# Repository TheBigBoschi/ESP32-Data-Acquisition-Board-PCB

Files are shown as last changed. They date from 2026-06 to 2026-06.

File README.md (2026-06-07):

# ESP32-Data-Acquisition-Board-PCB
Custom PCB holding an ESP32, various sensor, a LoRa transmitter and the power management to run off a single lithium battery, charged by solar power.

To keep the development time short for this first revision I have made extensive use of various commercial modules, such as a TP4056 module, a few TPS63020 and a CN3791 to handle the power conversion. In the second revision they will be integrated directly on the board.

Particular care has been taken to properly decouple the ESP32 power supply, as a switching regulators are slow to react to the sudden bursts of energy required by the ESP32 transmitting data, and various capacitor have been added to give time to the regulator to respond.

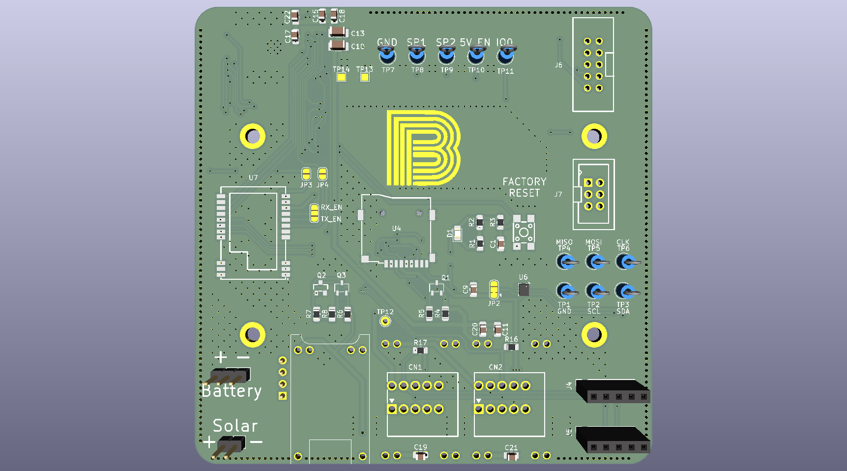
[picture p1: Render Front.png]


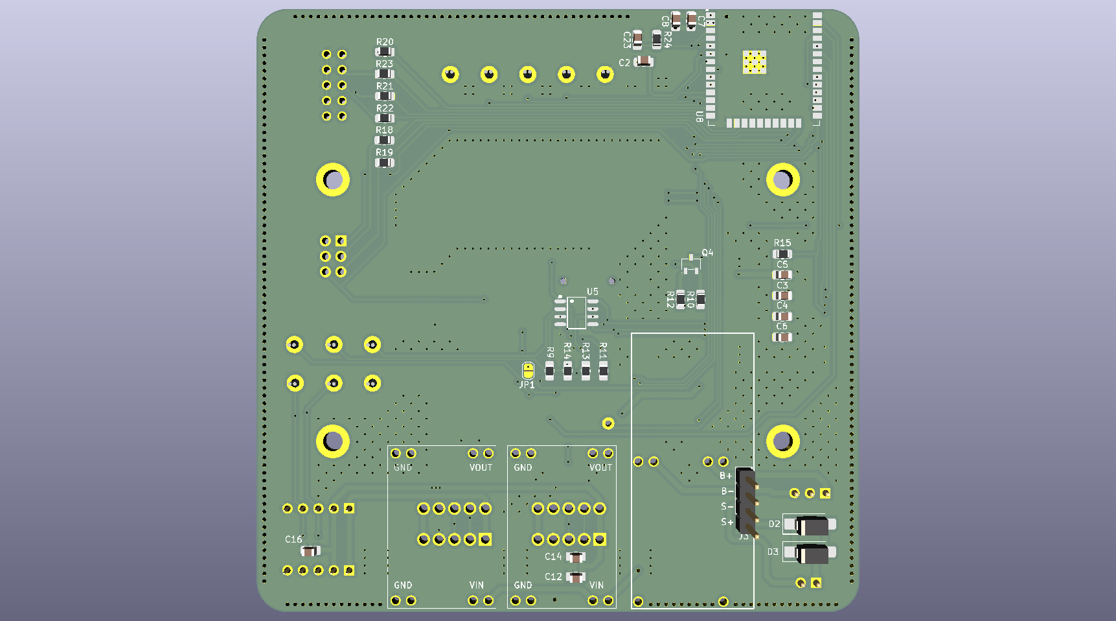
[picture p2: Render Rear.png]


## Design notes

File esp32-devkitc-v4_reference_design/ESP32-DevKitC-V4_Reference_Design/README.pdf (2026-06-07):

请使⽤用以下⼯工具打开原理理图和 PCB ⽂文件 / Use the following tools to open schematics and PCB files: SCH: Cadence/OrCAD Capture V16.6
PCB: Mentor Graphics/Pads VⅩ.2

修订历史 / Revision History

- 2018.06
- 更更新原理理图和 BOM，移除 C15。更更多信息请查看 ESP32-DevKitC ⼊入⻔门指南。/ (http://esp-idf.readthedocs.io/en/latest/get-started/get-started-devkitc.html) Removed C15 from schematics and BOM list. More information can be found in ESP32-DevKitC Getting Started Guide.) (http://esp-idf.readthedocs.io/en/latest/get-started/get-started-devkitc.html)
- 增加针对 ESP32-WROOM-32D、ESP32-WROOM-32U 和 ESP32-SOLO-1 模组的 BOM。/ Added the BOM lists for modules ESP32-WROOM-32D, ESP32-WROOM-32U and ESP32-SOLO-1.
- 2018.01
- ⾸首次发布。/
First release.

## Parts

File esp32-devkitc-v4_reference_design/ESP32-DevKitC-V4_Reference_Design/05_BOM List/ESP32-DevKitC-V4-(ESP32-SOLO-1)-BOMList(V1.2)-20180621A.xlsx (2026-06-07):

ESP32-DevKitC-V4 BOMList(V1.2)
ID | Qty | Ref Des | Value | Package | ICs | Description
1 | 3 | C1, C3, C21 | 22 uF/10V (20%) | 0603 | Capacitor | Ceramic Capacitor
2 | 4 | C9, C14, C19, C22 | 0.1 uF/50V (10%) | 0402 | Capacitor | Ceramic Capacitor
3 | 1 | C20 | 4.7 uF/6.3V (10%) | 0402 | Capacitor | Ceramic Capacitor
4 | 1 | D1 | RED LED | 0603 | Diode | light-emitting diode: Red
5 | 1 | D2 | ESP-WROOM-32 | ESP32_MODULE | Module | ESP32-SOLO-1 (3.3V 32 Mbit)
6 | 1 | D3 | BAT760-7 | SOD323 | Diode | Schottky Diode, Vrrm=30V, Vr=21V, I=1A, IFSM=5.5A
7 | 3 | D4, D5, D6 | LESD5D5.0CT1G | SOD-523 | Diode | ESD, TVS Diode, 5V
8 | 1 | J1 | Micro USB Type B Female 5 Pin DIP/插件 | USB_5P | Connector | Micro USB
9 | 2 | Q1, Q2 | S8050 | SOT-23-3 | Transistor | Transistor
10 | 2 | R2, R24 | 2K (5%) | 0402 | Resistor | Chip Resistors
11 | 3 | R11, R21, R22 | 10K (5%) | 0402 | Resistor | Chip Resistors
12 | 2 | R17, R18 | 0R (5%) | 0402 | Resistor | Chip Resistors
13 | 1 | R25 | 22.1K (5%) | 0402 | Resistor | Chip Resistors
14 | 1 | R26 | 47.5K (5%) | 0402 | Resistor | Chip Resistors
15 | 2 | SW1, SW2 | SW push button | Tact Switch | Tact Switch | 复位按键，2 脚，3x4x2，贴片 (reset button, 2-pin, 3x4x2, SMT)
16 | 2 | J2, J3 | CON19X1_2P54 | CON19_2P54 | Connector | Male PCB Single Row Straight Header Connector, 2.54 mm Pitch, 19 Pins
17 | 1 | U1 | CP2102N-A01-GQFN28 | CP2102_QFN_28P | Interface ICs | USB-to-UART, USB2.0 full speed, data rate up to 3M baud
18 | 1 | U2 | AMS1117-3.3 | SOT-223 | Power ICs | LDO, 5V 转 3.3V 固定输出, 1A, SOT-223 (LDO, 5V/3.3V, 1A, SOT-223)

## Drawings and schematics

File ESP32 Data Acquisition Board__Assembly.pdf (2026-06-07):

## GND SP1 SP2 5V_EN IO0

# JP4 C13

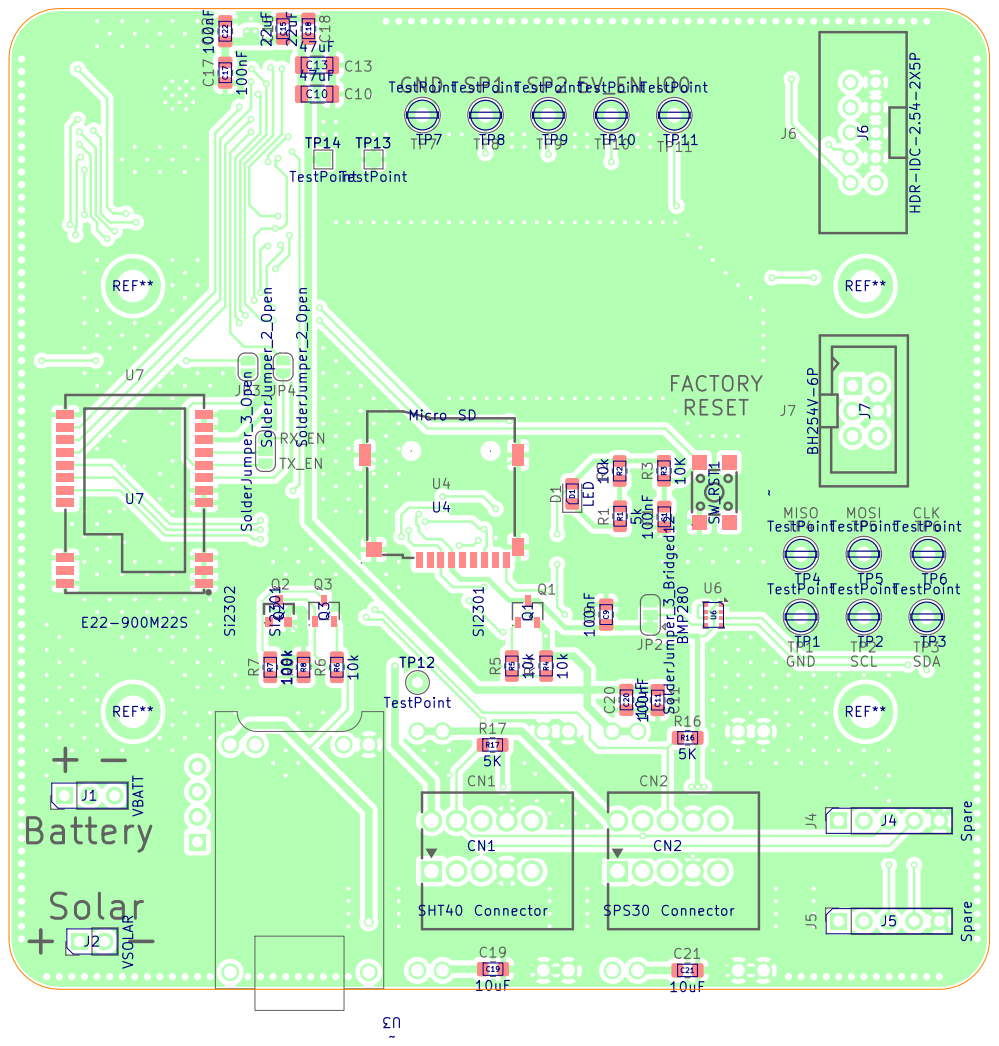
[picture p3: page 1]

Sheet: Colored TOP
File: ESP32 Data Acquisition Board.kicad_pcb
Title:
KiCad E.D.A. 10.0.3

ESP32-WROOM-32D U8 | M7F D2
C12 | 100nF C7 | CN3791 J3 10uF C8

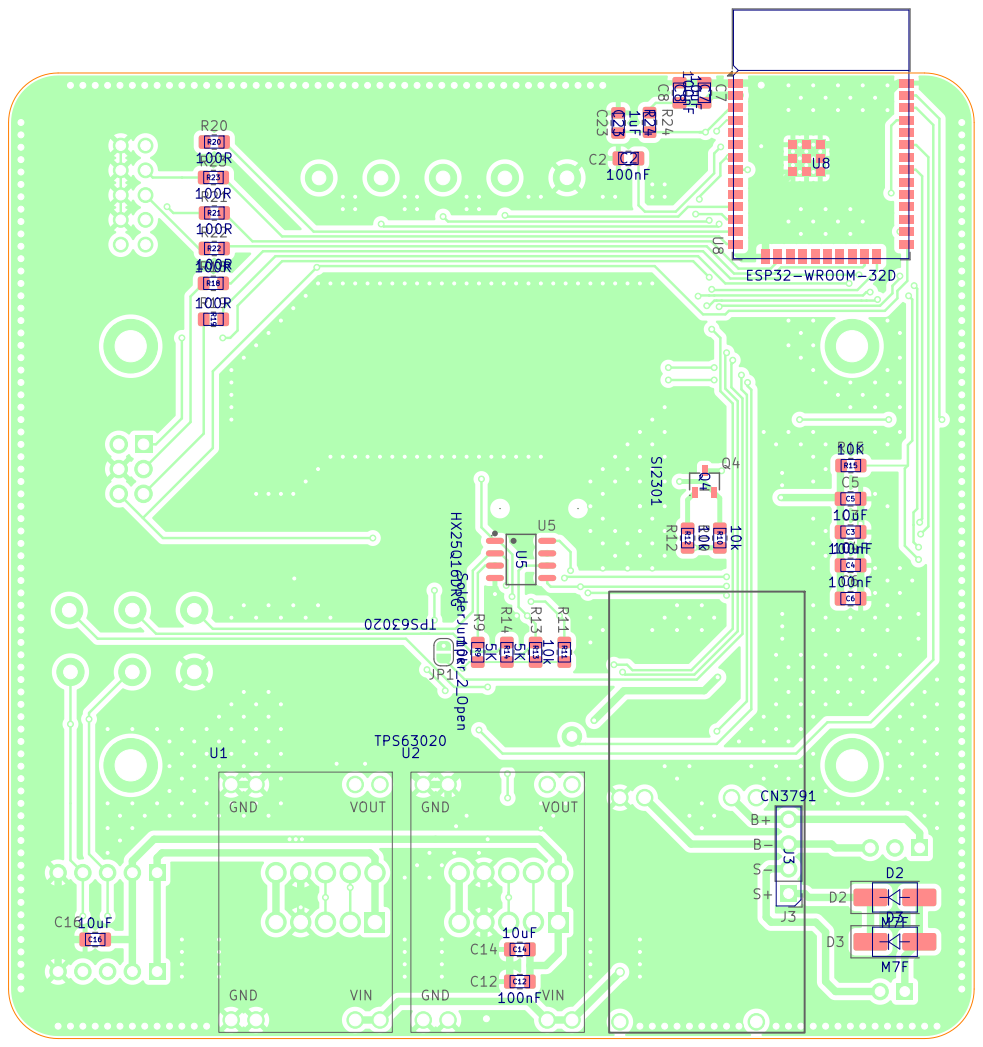
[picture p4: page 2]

Sheet: Colored BOT
File: ESP32 Data Acquisition Board.kicad_pcb
Title:
KiCad E.D.A. 10.0.3

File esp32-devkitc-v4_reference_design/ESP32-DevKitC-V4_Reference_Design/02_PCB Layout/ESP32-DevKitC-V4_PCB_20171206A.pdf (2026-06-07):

D1D¹x1 D¹x2 J2J2x1 J2x2 J2x3 J2x4 J2x5 J2x6 J2x7 J2x8 J2x9 J2x10 J2x11 J2x12 J2x13 J2x14 J2x15 J2x16 J2x17 J2x18 J2x19

J3J3x1 J3x2 J3x3 J3x4 J3x5 J3x6 J3x7 J3x8 J3x9 J3x10 J3x11 J3x12 J3x13 J3x14 J3x15 J3x16 J3x17 J3x18 J3x19

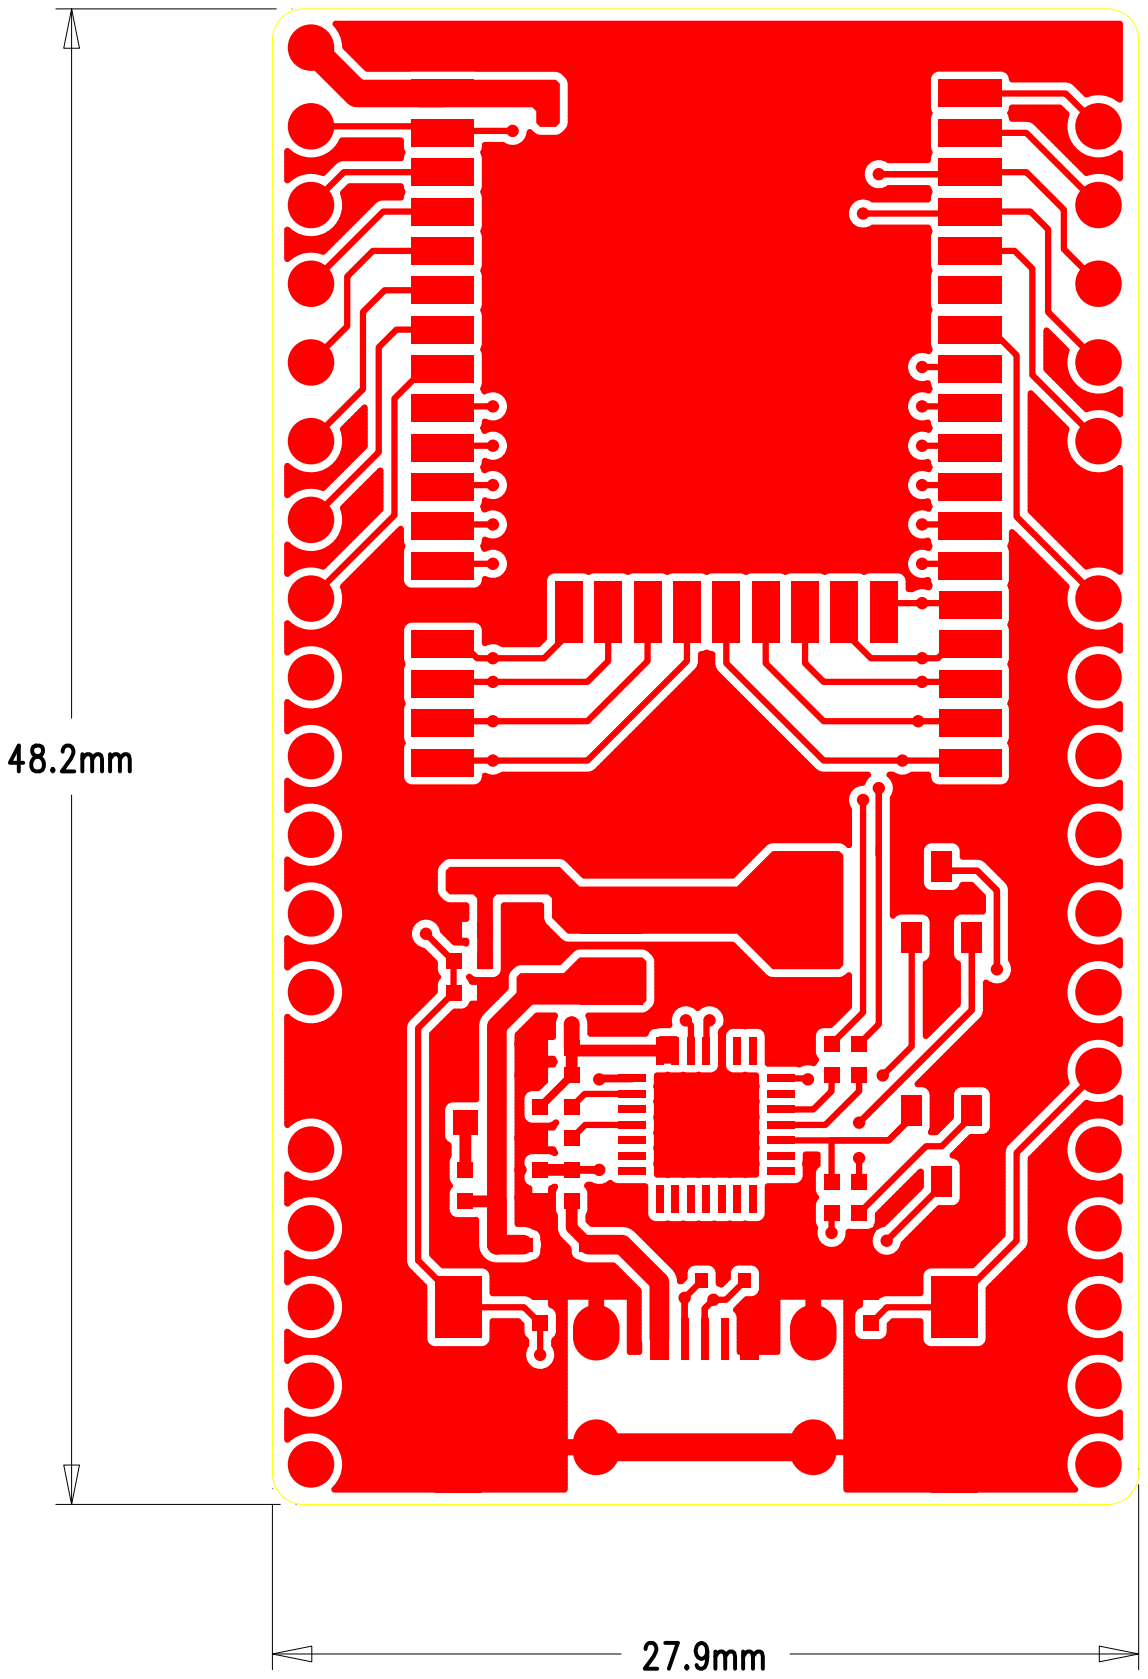
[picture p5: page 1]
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

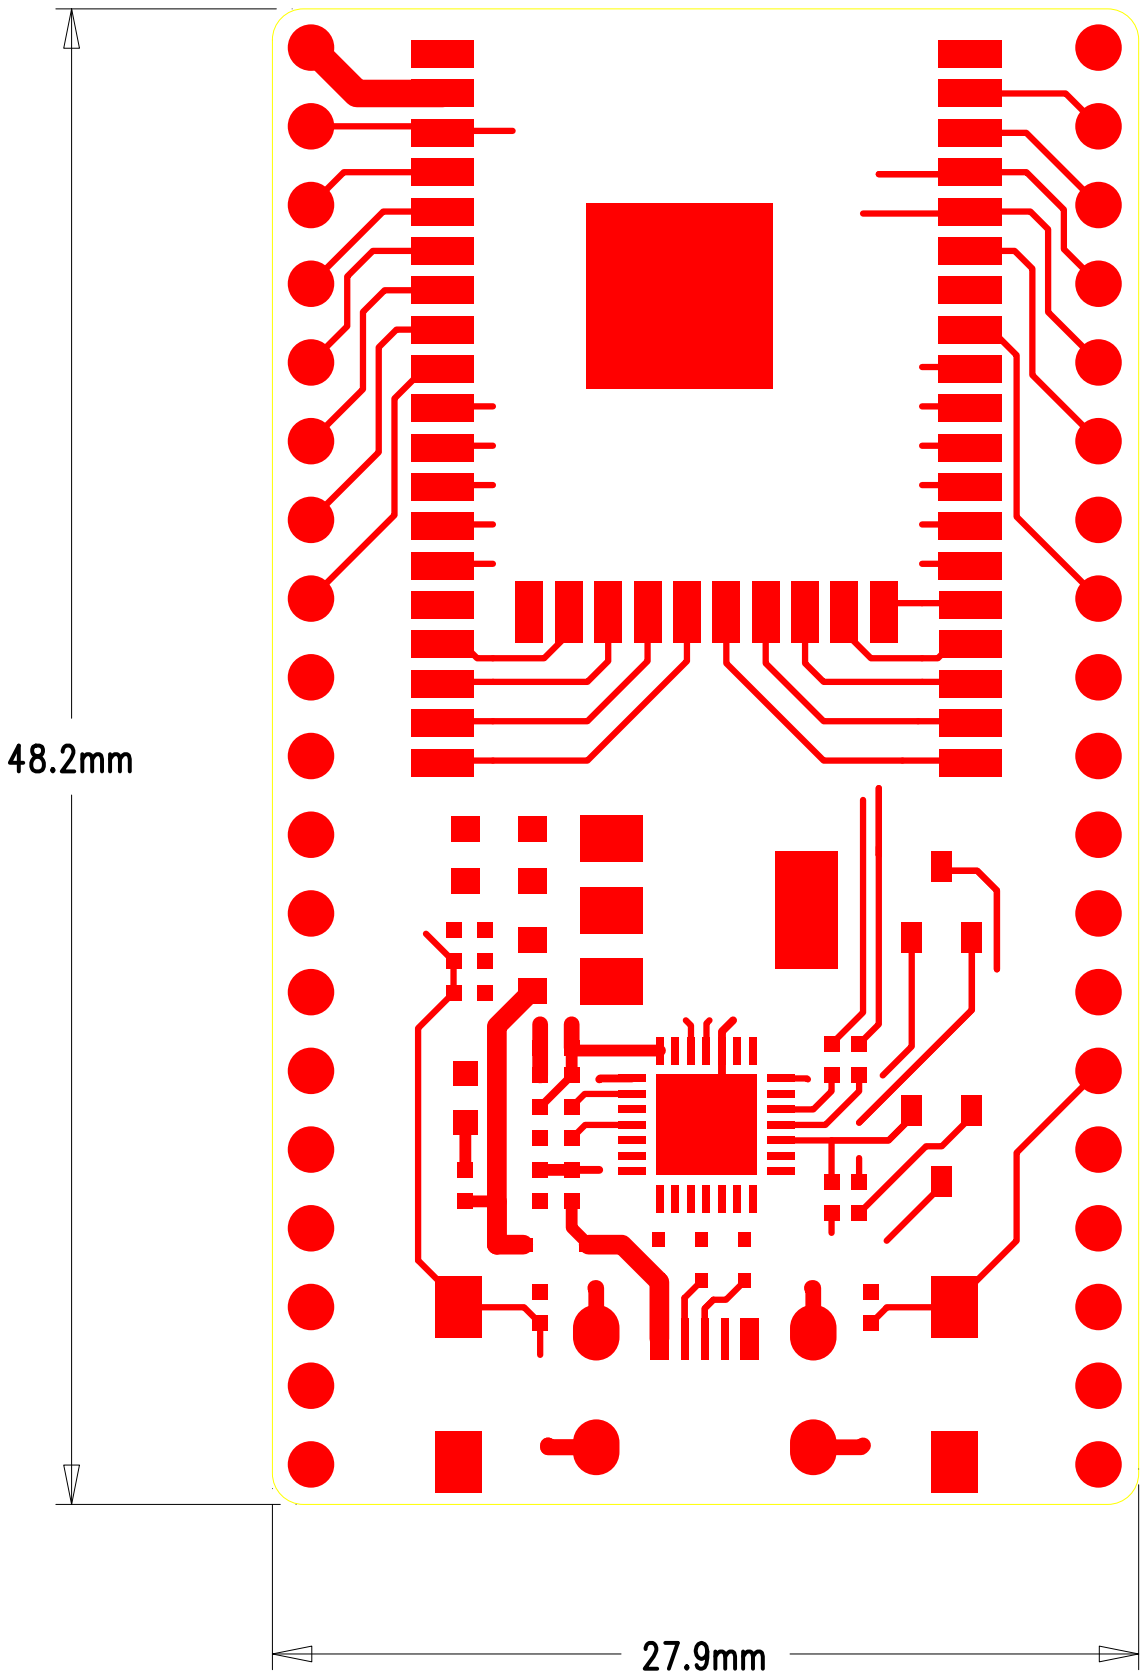
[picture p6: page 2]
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

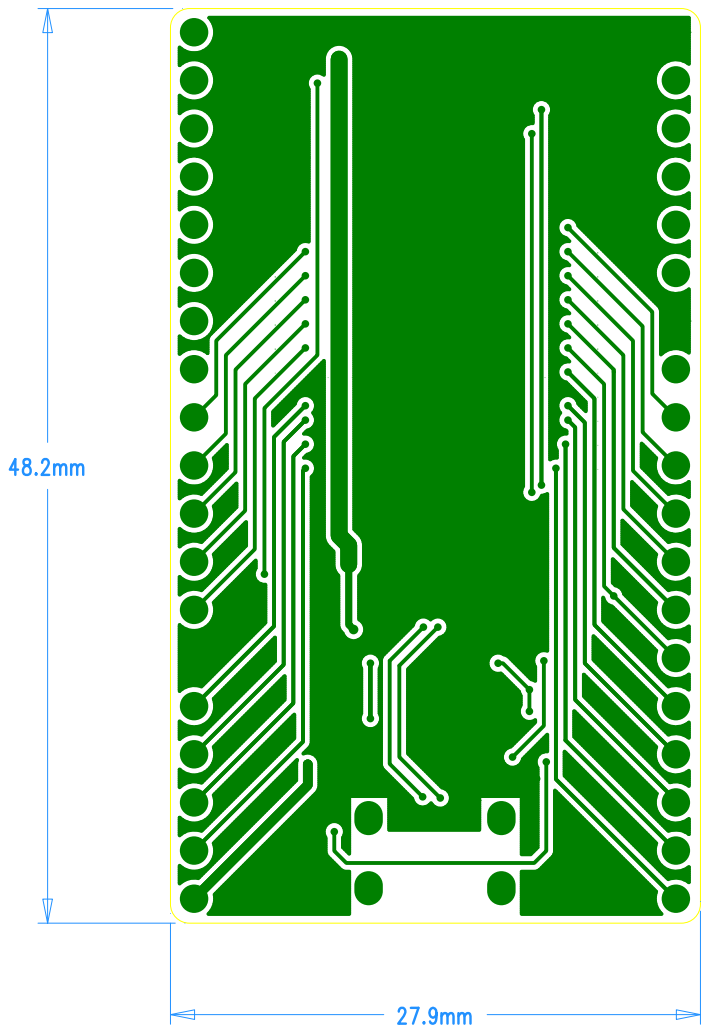
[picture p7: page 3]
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

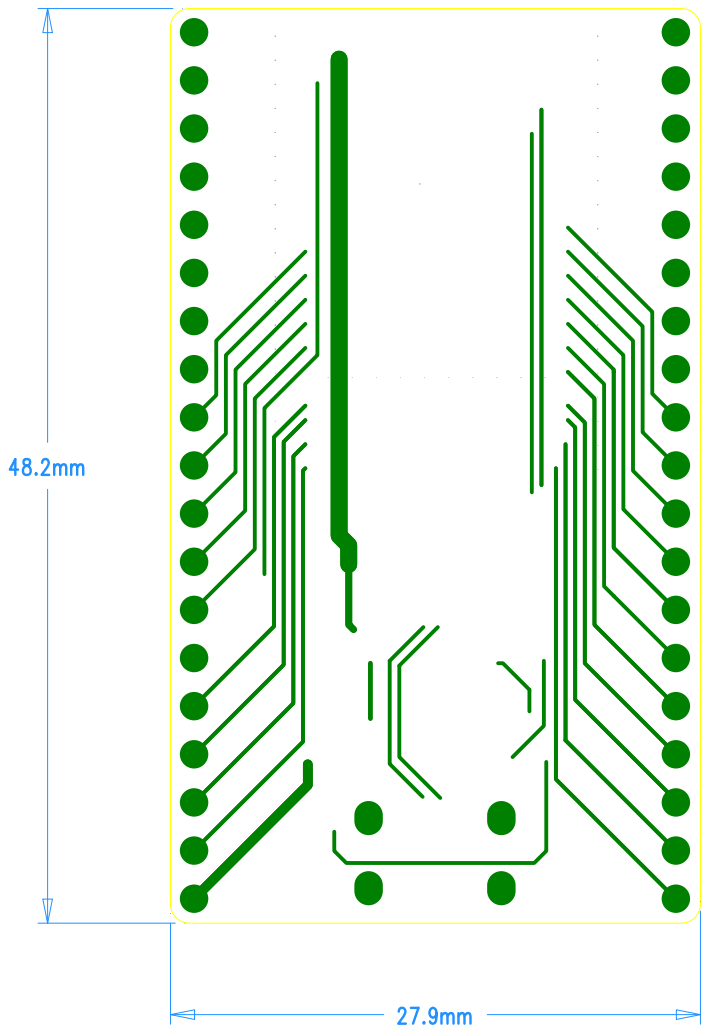
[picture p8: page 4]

# RF Antenna

D2

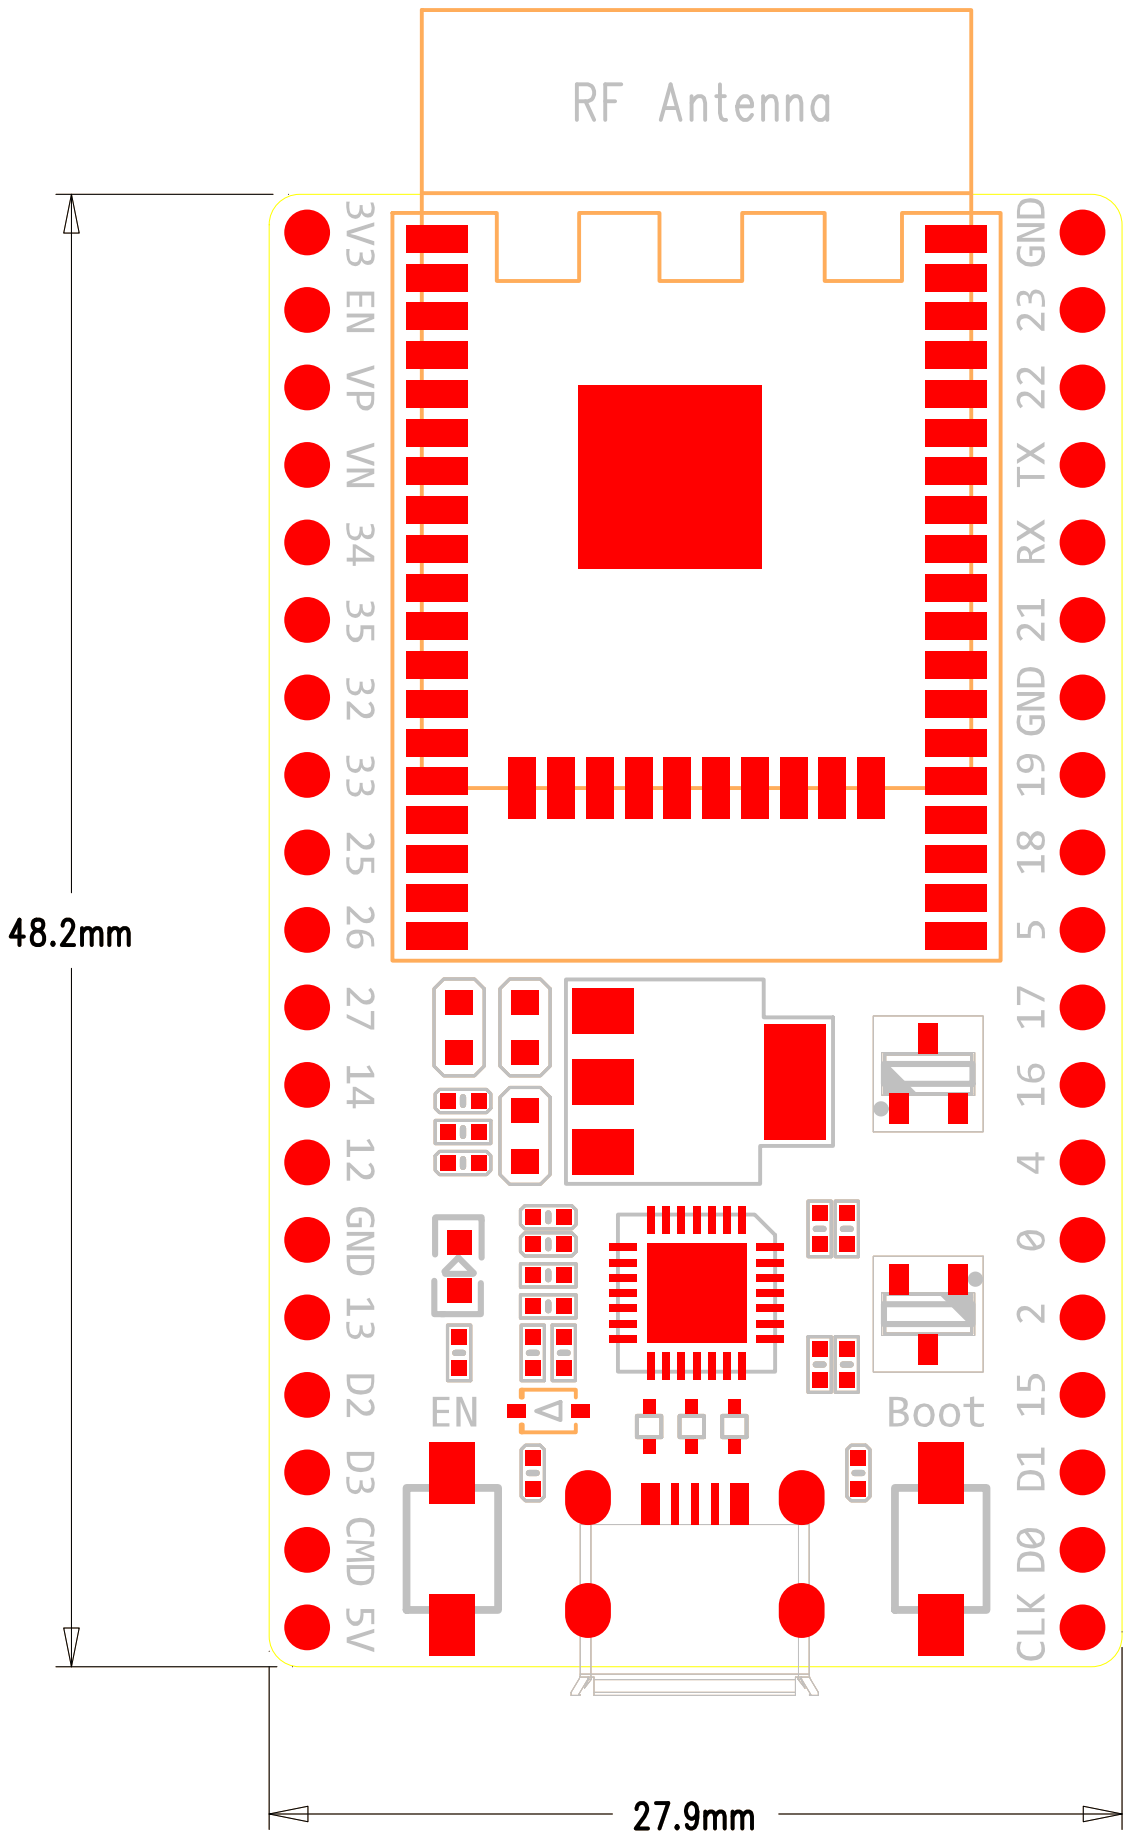
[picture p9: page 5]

3V3 EN VP VN 34 35 32 33 25 26 27 14 12 CMD 13 D2 D3 5V

GND 22 TX RX 21 GND 19 18 16 5 17 4 0 2 15 23 CLK D0 D1

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

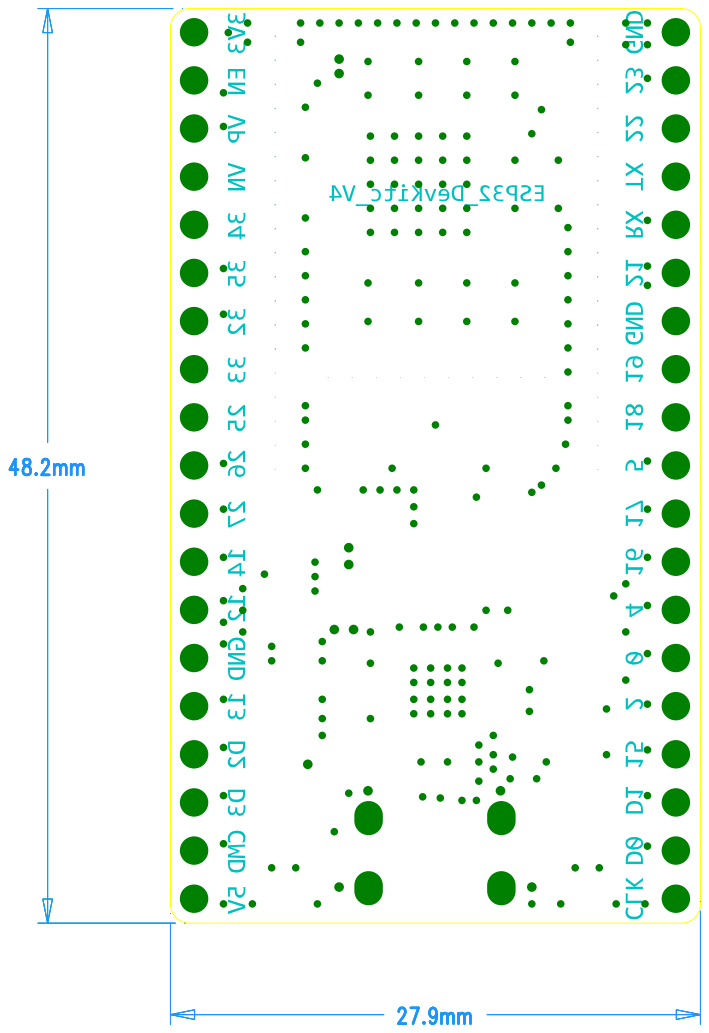
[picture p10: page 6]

3V3 EN VP VN 34 35 32 33 25 26 27 14 12 GND 13 D2 D3 CMD 5V

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

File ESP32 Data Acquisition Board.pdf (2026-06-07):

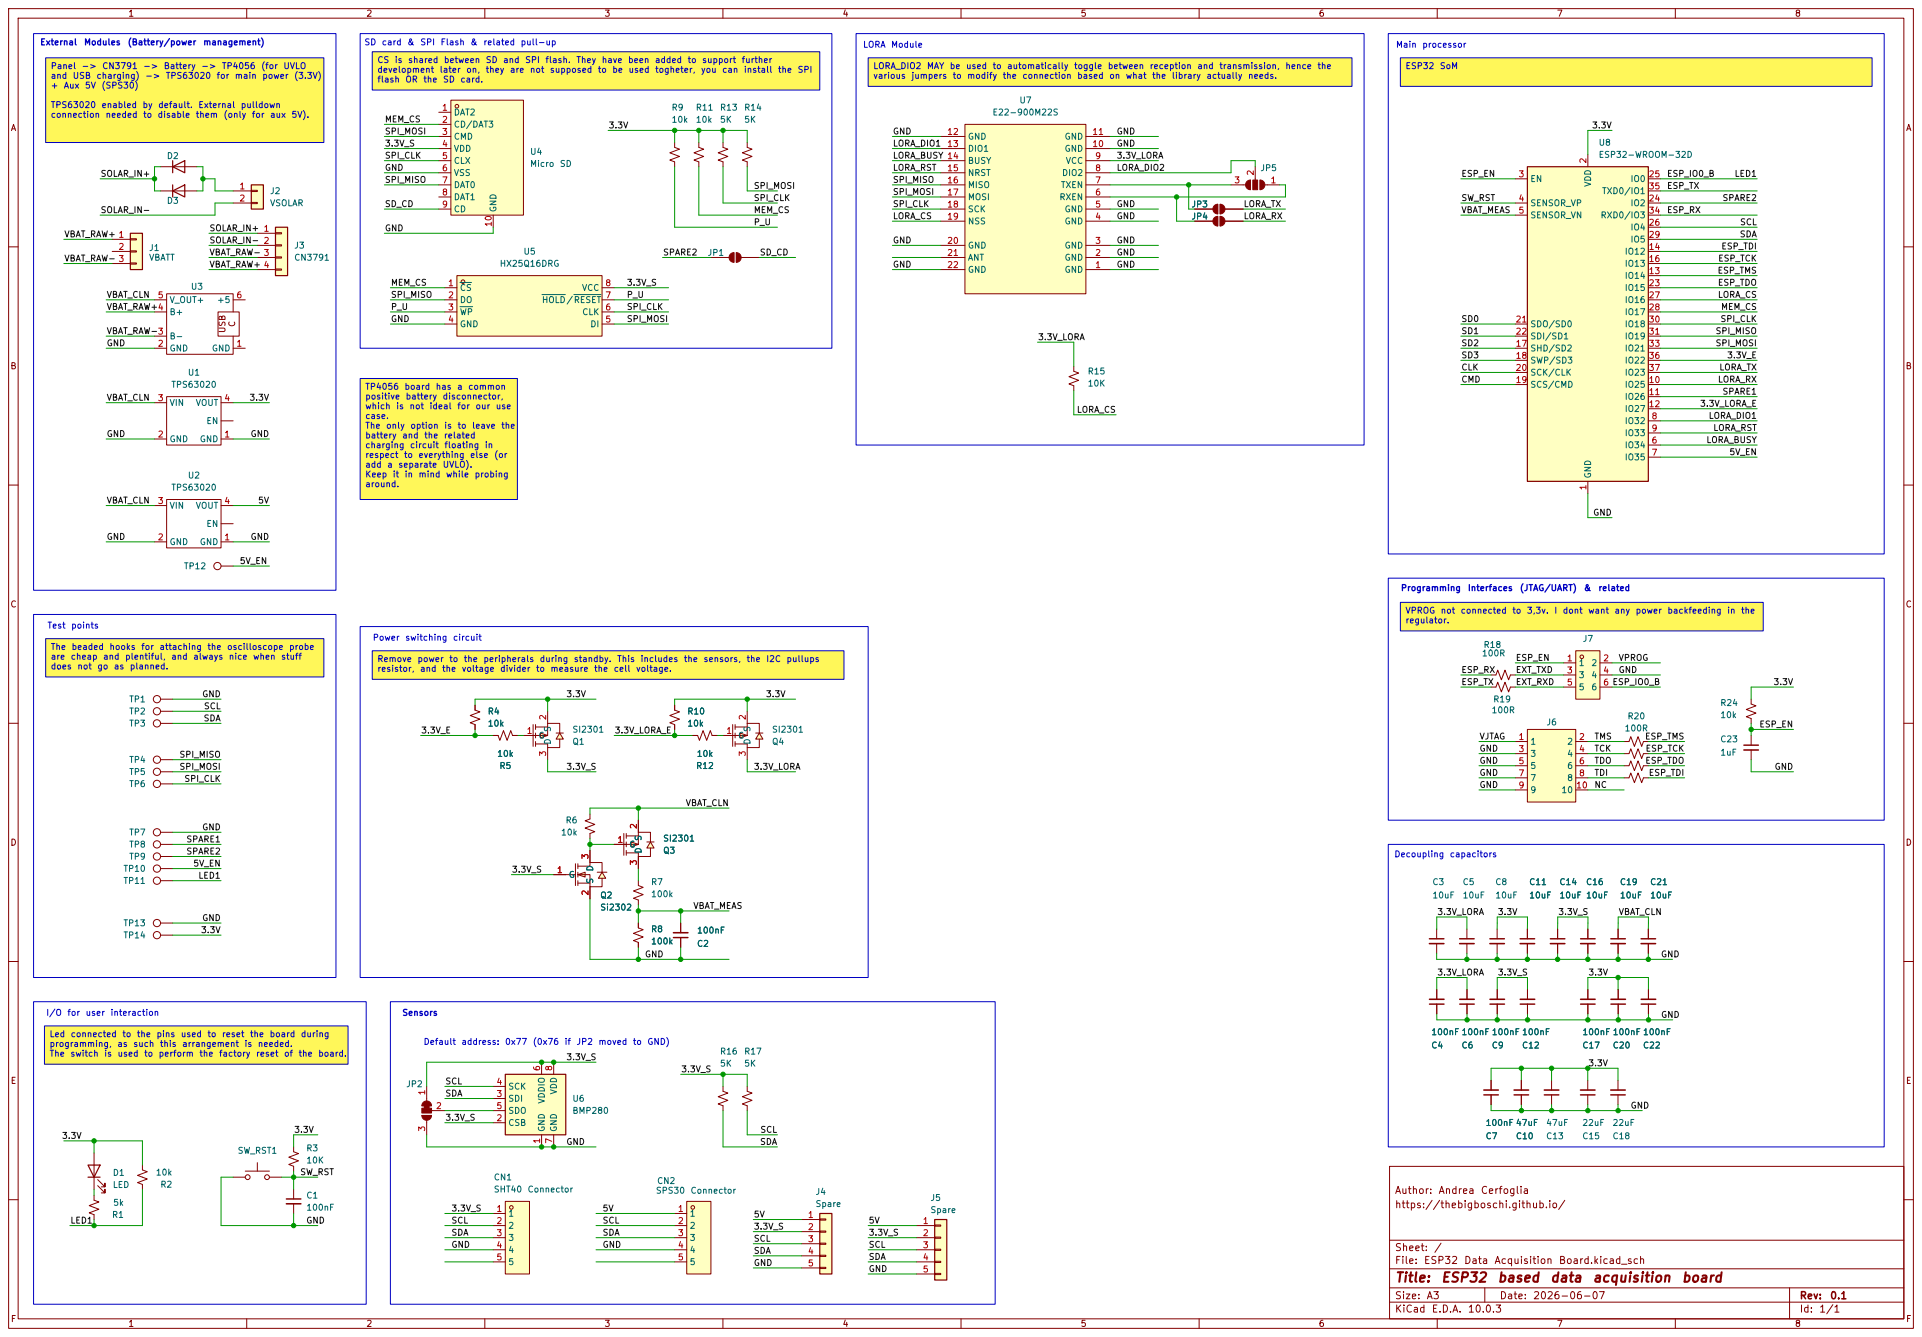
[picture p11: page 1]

Panel -> CN3791 -> Battery -> TP4056 (for UVLO
and USB charging) -> TPS63020 for main power (3.3V) + Aux 5V (SPS30) TPS63020 enabled by default. External pulldown

various jumpers to modify the connection based on what the library actually needs. Remove power to the peripherals during standby. This includes the sensors, the I2C pullups

TP4056 board has a common
positive battery disconnector, which is not ideal for our use

case. The only option is to leave the battery and the related

charging circuit floating in
respect to everything else (or add a separate UVLO).
3.3V SCL

Keep it in mind while probing
around.

Programming Interfaces (JTAG/UART) & related

regulator. The beaded hooks for attaching the oscilloscope probe are cheap and plentiful, and always nice when stuff does not go as planned.
resistor, and the voltage divider to measure the cell voltage. Test points

Led connected to the pins used to reset the board during
programming, as such this arrangement is needed. The switch is used to perform the factory reset of the board.

Author: Andrea Cerfoglia
https://thebigboschi.github.io/

Sheet: /
File: ESP32 Data Acquisition Board.kicad_sch
Title: ESP32 based data acquisition board

Size: A3 | Rev: 0.1
KiCad E.D.A. 10.0.3 | Id: 1/1 | F Date: 2026-06-07

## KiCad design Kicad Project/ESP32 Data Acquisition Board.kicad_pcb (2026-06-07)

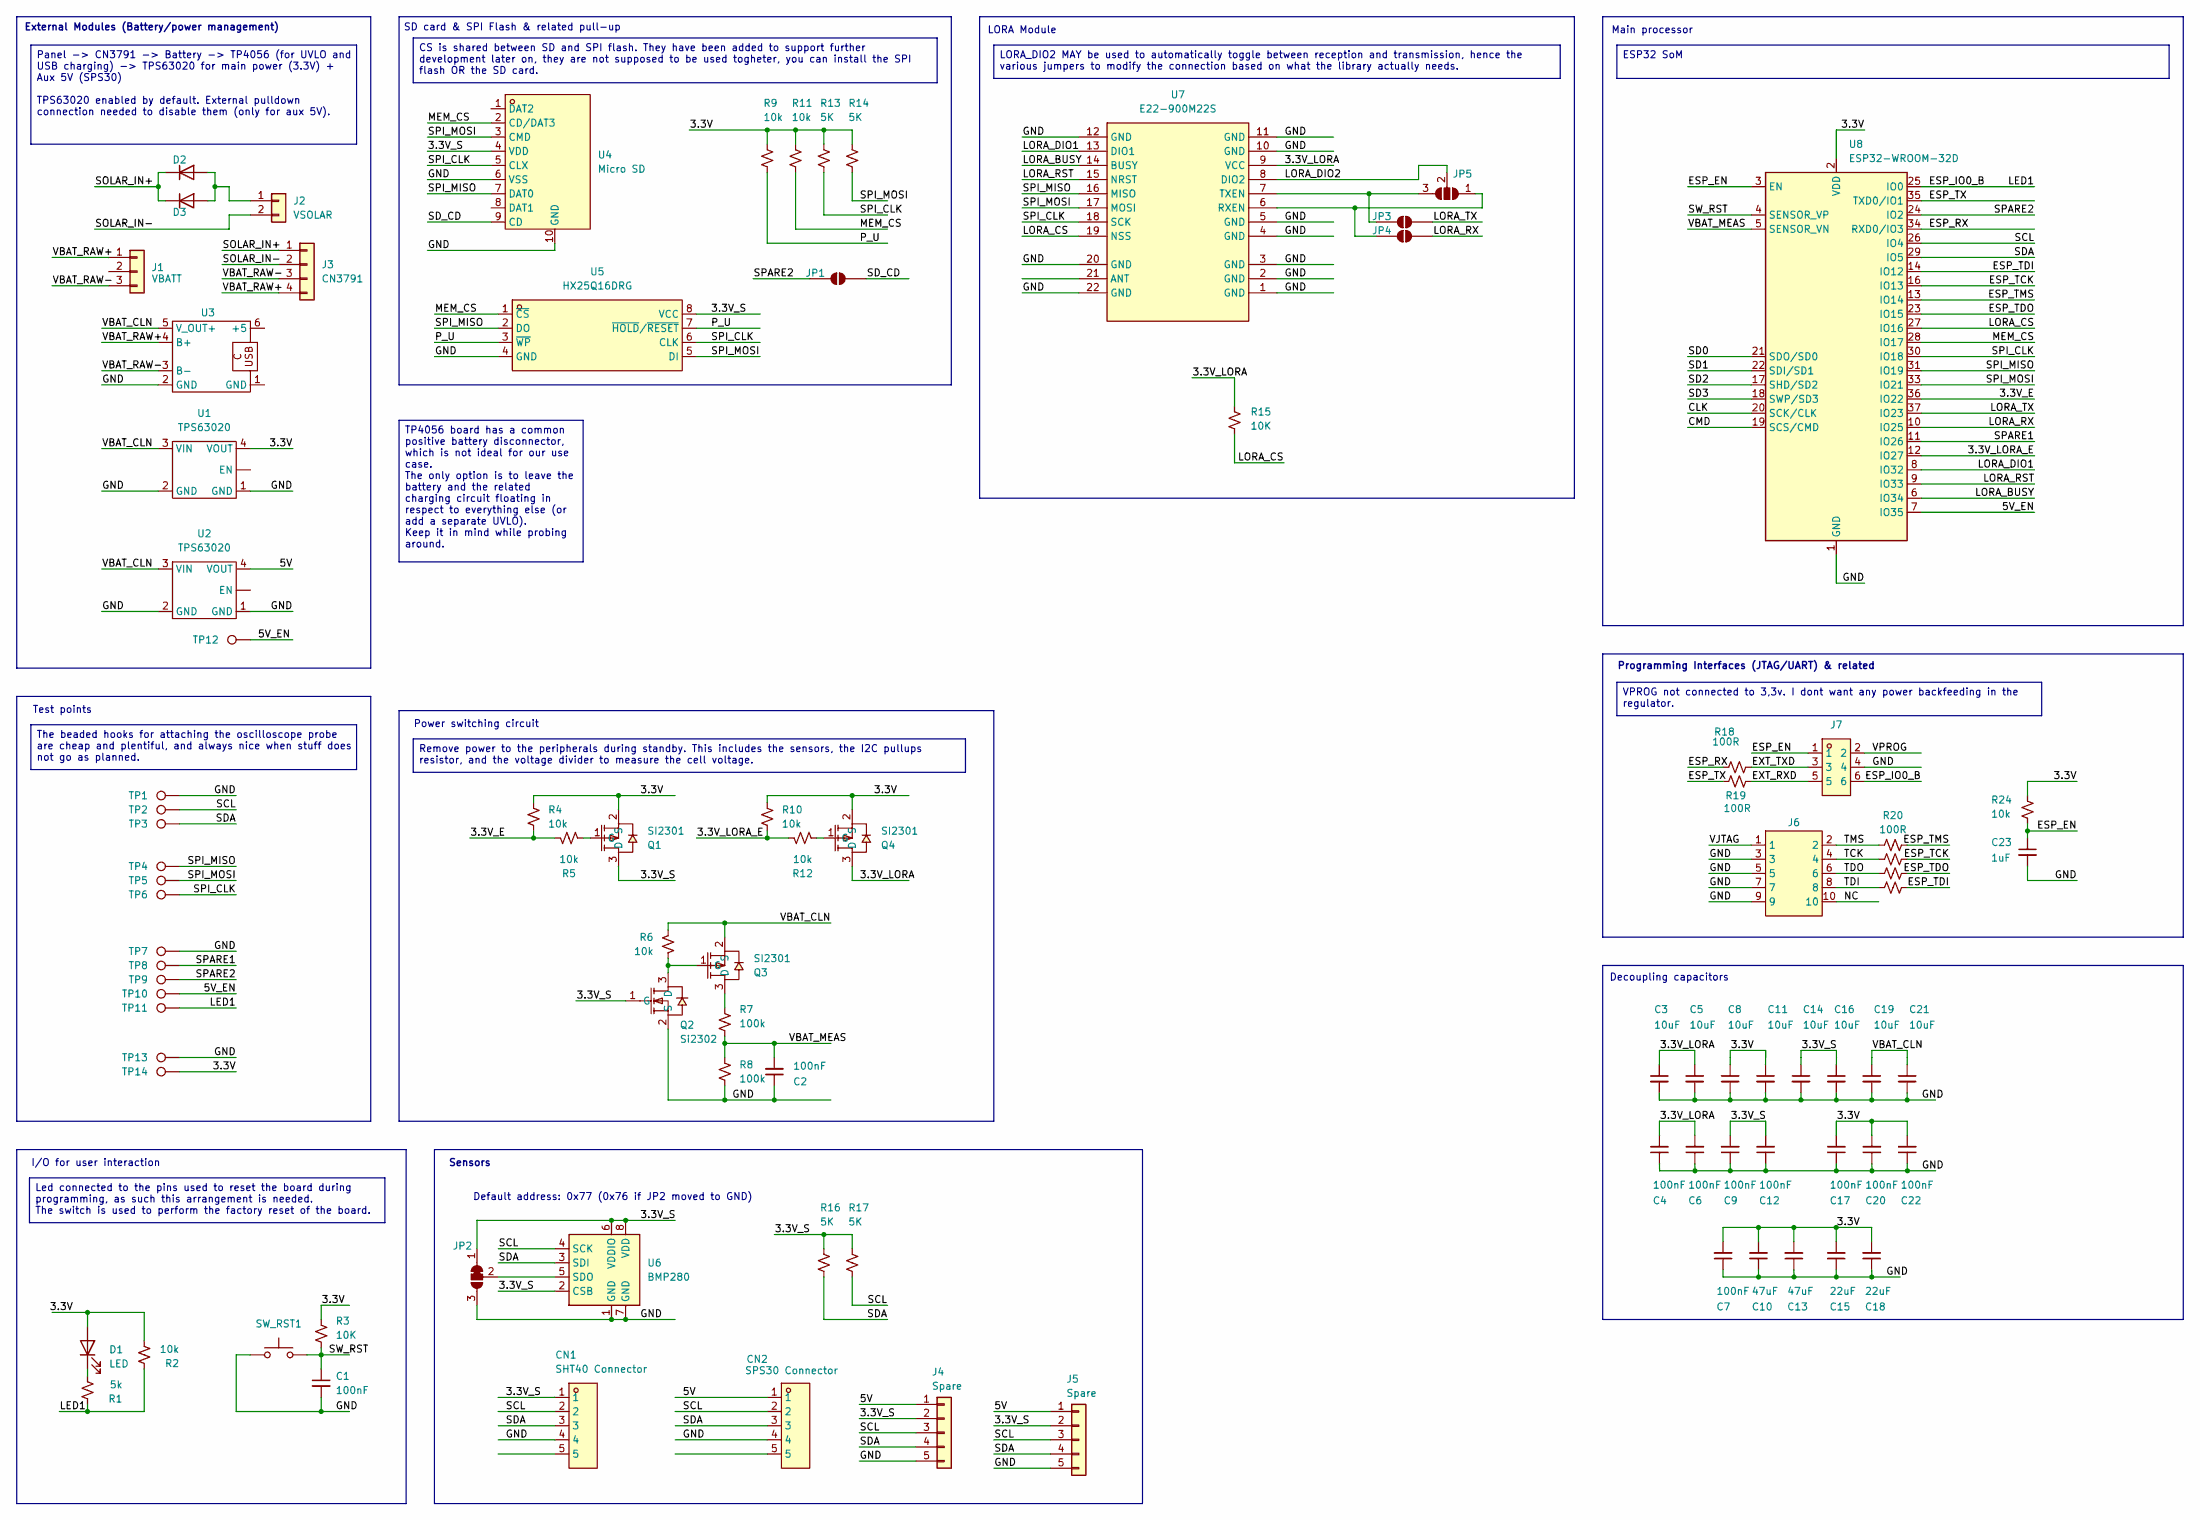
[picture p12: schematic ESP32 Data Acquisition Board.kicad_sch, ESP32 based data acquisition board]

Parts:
C1, C2, C4, C6, C7, C9, C12, C17, C20, C22: 100nF; C_0805_2012Metric_Pad1.18x1.45mm_HandSolder
C3, C5, C8, C11, C14, C16, C19, C21: 10uF; C_0805_2012Metric_Pad1.18x1.45mm_HandSolder
C10, C13: 47uF; C_1206_3216Metric_Pad1.33x1.80mm_HandSolder
C15, C18: 22uF; C_0805_2012Metric_Pad1.18x1.45mm_HandSolder
C23: 1uF; C_0805_2012Metric_Pad1.18x1.45mm_HandSolder
CN1: SHT40 Connector; CONN-TH_5P-P2.54_KF141R-2.54-5P; MPN KF141R-2.54-5P; LCSC Part C475127
CN2: SPS30 Connector; CONN-TH_5P-P2.54_KF141R-2.54-5P; MPN KF141R-2.54-5P; LCSC Part C475127
D1: LED; LED_0805_2012Metric_Pad1.15x1.40mm_HandSolder
D2, D3: M7F; D_SMA_Handsoldering
J1: VBATT; PinHeader_1x03_P2.54mm_Vertical
J2: VSOLAR; PinHeader_1x02_P2.54mm_Vertical
J3: CN3791; PinHeader_1x04_P2.54mm_Vertical
J4, J5: Spare; PinSocket_1x05_P2.54mm_Vertical
J6: HDR-IDC-2.54-2X5P; IDC-TH_10P-P2.54_C5665; MPN 2.54-2*5P简牛; LCSC Part C5665
J7: BH254V-6P; IDC-TH_6P-P2.54-V-R2-C3-S2.54; MPN BH254V-6P; LCSC Part C492441
JP1, JP3, JP4: SolderJumper_2_Open; SolderJumper-2_P1.3mm_Open_RoundedPad1.0x1.5mm
JP2: SolderJumper_3_Bridged12; SolderJumper-3_P1.3mm_Bridged12_RoundedPad1.0x1.5mm
JP5: SolderJumper_3_Open; SolderJumper-3_P1.3mm_Open_RoundedPad1.0x1.5mm_NumberLabels
Q1, Q3, Q4: SI2301; SOT-23-3_L3.0-W1.7-P0.95-LS2.9-BR; MPN SI2301CDS-T1-GE3; LCSC Part C10487
Q2: Si2302; SOT-23_L2.9-W1.3-P1.90-LS2.4-BR; MPN Si2302CDS-T1-GE3; LCSC Part C10488
R1: 5k; R_0805_2012Metric_Pad1.20x1.40mm_HandSolder
R2, R4, R5, R6, R9, R10, R11, R12, R24: 10k; R_0805_2012Metric_Pad1.20x1.40mm_HandSolder
R3, R15: 10K; R_0805_2012Metric_Pad1.20x1.40mm_HandSolder
R7, R8: 100k; R_0805_2012Metric_Pad1.20x1.40mm_HandSolder
R13, R14, R16, R17: 5K; R_0805_2012Metric_Pad1.20x1.40mm_HandSolder
R18, R19, R20, R21, R22, R23: 100R; R_0805_2012Metric_Pad1.20x1.40mm_HandSolder
SW_RST1: SW-SMD_4P-L4.5-W4.5-P3.00-LS6.6; MPN TS110926045; LCSC Part C22375351
TP1, TP2, TP3, TP4, TP5, TP6, TP7, TP8, TP9, TP10, TP11: TestPoint; TestPoint_Loop_D3.50mm_Drill1.4mm_Beaded
TP12: TestPoint; TestPoint_THTPad_D2.0mm_Drill1.0mm
TP13, TP14: TestPoint; TestPoint_Pad_1.5x1.5mm
U1, U2: TPS63020
U3: TP4056 BOARD
U4: Micro SD; SIM-SMD_LX_XDFP-0090-012; MPN TF-CARD-9P; LCSC Part C53144700
U5: HX25Q16DRG; SOP-8_L4.9-W3.9-P1.27-LS6.0-BL; MPN HX25Q16DRG; LCSC Part C22439610
U6: BMP280; Bosch_LGA-8_2x2.5mm_P0.65mm_ClockwisePinNumbering
U7: E22-900M22S; WIRELM-SMD_E22-900M22S; MPN E22-900M22S; LCSC Part C411293
U8: ESP32-WROOM-32D

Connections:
/3.3V: C7.2, C8.1, C10.2, C11.1, C13.2, C15.2, C17.2, C18.2, C20.2, C22.2, D1.2 (A), Q1.2 (S), Q4.2 (S), R2.1, R3.2, R4.2, R9.2, R10.2, R11.2, R13.2, R14.2, R24.2, TP14.1 (1_1), U1.4 (VOUT), U8.2 (VDD)
/3.3V_E: R4.1, R5.1, U8.36 (IO22)
/3.3V_LORA: C3.1, C4.2, C5.1, C6.2, Q4.3 (D), R15.2, U7.9 (VCC)
/3.3V_LORA_E: R10.1, R12.1, U8.12 (IO27)
/3.3V_S: C9.2, C12.2, C14.1, C16.1, CN1.1, J4.2, J5.2, JP2.1 (A), Q1.3 (D), Q2.1 (G), R16.2, R17.2, U4.4 (VDD), U5.8 (VCC), U6.2 (CSB), U6.6 (VDDIO), U6.8 (VDD)
/5V: CN2.1, J4.1, J5.1, U2.4 (VOUT)
/5V_EN: TP10.1 (1_1), TP12.1 (1_1), U8.7 (IO35)
/CLK: U8.20 (SCK/CLK)
/CMD: U8.19 (SCS/CMD)
/ESP_EN: C23.1, J7.1, R24.1, U8.3 (EN)
/ESP_IO0_B: J7.6, R1.2, R2.2, TP11.1 (1_1), U8.25 (IO0)
/ESP_RX: R18.1, U8.34 (RXD0/IO3)
/ESP_TCK: R21.2, U8.16 (IO13)
/ESP_TDI: R23.2, U8.14 (IO12)
/ESP_TDO: R22.2, U8.23 (IO15)
/ESP_TMS: R20.2, U8.13 (IO14)
/ESP_TX: R19.1, U8.35 (TXD0/IO1)
/EXT_RXD: J7.5, R19.2
/EXT_TXD: J7.3, R18.2
/GND: C1.2, C2.1, C3.2, C4.1, C5.2, C6.1, C7.1, C8.2, C9.1, C10.1, C11.2, C12.1, C13.1, C14.2, C15.1, C16.2, C17.1, C18.1, C19.2, C20.1, C21.2, C22.1, C23.2, CN1.4, CN2.4, J4.5, J5.5, J6.3, J6.5, J6.7, J6.9, J7.4, JP2.3 (B), Q2.2 (S), R8.1, SW_RST1.1, TP1.1 (1_1), TP7.1 (1_1), TP13.1 (1_1), U1.1 (GND), U1.2 (GND), U2.1 (GND), U2.2 (GND), U3.2 (GND), U4.6 (VSS), U4.10 (GND), U5.4 (GND), U6.1 (GND), U6.7 (GND), U7.1 (GND), U7.2 (GND), U7.3 (GND), U7.4 (GND), U7.5 (GND), U7.10 (GND), U7.11 (GND), U7.12 (GND), U7.20 (GND), U7.22 (GND), U8.1 (GND), U8.15 (GND), U8.38 (GND), U8.39 (GND)
/LORA_BUSY: U7.14 (BUSY), U8.6 (IO34)
/LORA_CS: R15.1, U7.19 (NSS), U8.27 (IO16)
/LORA_DIO1: U7.13 (DIO1), U8.8 (IO32)
/LORA_DIO2: JP5.2 (C), U7.8 (DIO2)
/LORA_RST: U7.15 (NRST), U8.9 (IO33)
/LORA_RX: JP4.2 (B), U8.10 (IO25)
/LORA_TX: JP3.2 (B), U8.37 (IO23)
/MEM_CS: R11.1, U4.2 (CD/DAT3), U5.1 (~CS), U8.28 (IO17)
/NC: J6.10
/P_U: R9.1, U5.3 (~WP), U5.7 (~HOLD/~RESET)
/SCL: CN1.2, CN2.2, J4.3, J5.3, R17.1, TP2.1 (1_1), U6.4 (SCK), U8.26 (IO4)
/SD0: U8.21 (SDO/SD0)
/SD1: U8.22 (SDI/SD1)
/SD2: U8.17 (SHD/SD2)
/SD3: U8.18 (SWP/SD3)
/SDA: CN1.3, CN2.3, J4.4, J5.4, R16.1, TP3.1 (1_1), U6.3 (SDI), U8.29 (IO5)
/SD_CD: JP1.2 (B), U4.9 (CD)
/SOLAR_IN+: D2.1 (K), D3.1 (K), J3.1
/SOLAR_IN-: J2.2, J3.2
/SPARE1: TP8.1 (1_1), U8.11 (IO26)
/SPARE2: JP1.1 (A), TP9.1 (1_1), U8.24 (IO2)
/SPI_CLK: R13.1, TP6.1 (1_1), U4.5 (CLX), U5.6 (CLK), U7.18 (SCK), U8.30 (IO18)
/SPI_MISO: TP4.1 (1_1), U4.7 (DAT0), U5.2 (DO), U7.16 (MISO), U8.31 (IO19)
/SPI_MOSI: R14.1, TP5.1 (1_1), U4.3 (CMD), U5.5 (DI), U7.17 (MOSI), U8.33 (IO21)
/SW_RST: C1.1, R3.1, SW_RST1.2, U8.4 (SENSOR_VP)
/TCK: J6.4, R21.1
/TDI: J6.8, R23.1
/TDO: J6.6, R22.1
/TMS: J6.2, R20.1
/VBAT_CLN: C19.1, C21.1, Q3.2 (S), R6.2, U1.3 (VIN), U2.3 (VIN), U3.5 (V_OUT+)
/VBAT_MEAS: C2.2, R7.1, R8.2, U8.5 (SENSOR_VN)
/VBAT_RAW+: J1.1, J3.4, U3.4 (B+)
/VBAT_RAW-: J1.3, J3.3, U3.3 (B-)
/VJTAG: J6.1
/VPROG: J7.2
unnamed: D1.1 (K), R1.1
unnamed: D2.2 (A), D3.2 (A), J2.1
unnamed: JP2.2 (C), U6.5 (SDO)
unnamed: JP3.1 (A), JP5.3 (B), U7.7 (TXEN)
unnamed: JP4.1 (A), JP5.1 (A), U7.6 (RXEN)
unnamed: Q1.1 (G), R5.2
unnamed: Q2.3 (D), Q3.1 (G), R6.1
unnamed: Q3.3 (D), R7.2
unnamed: Q4.1 (G), R12.2

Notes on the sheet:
Main processor
Test points
SD card & SPI Flash & related pull-up
Power switching circuit
LORA Module
External Modules (Battery/power management)
Decoupling capacitors
Default address: 0x77 (0x76 if JP2 moved to GND)
Sensors
Programming Interfaces (JTAG/UART) & related
I/O for user interaction
ESP32 SoM
LORA_DIO2 MAY be used to automatically toggle between reception and transmission, hence the various jumpers to modify the connection based on what the library actually needs.
Panel -> CN3791 -> Battery -> TP4056 (for UVLO and USB charging) -> TPS63020 for main power (3.3V) + Aux 5V (SPS30) TPS63020 enabled by default. External pulldown connection needed to disable them (only for aux 5V).
The beaded hooks for attaching the oscilloscope probe are cheap and plentiful, and always nice when stuff does not go as planned.
VPROG not connected to 3,3v. I dont want any power backfeeding in the regulator.
CS is shared between SD and SPI flash. They have been added to support further development later on, they are not supposed to be used togheter, you can install the SPI flash OR the SD card.
Led connected to the pins used to reset the board during programming, as such this arrangement is needed. The switch is used to perform the factory reset of the board.
TP4056 board has a common positive battery disconnector, which is not ideal for our use case. The only option is to leave the battery and the related charging circuit floating in respect to everything else (or add a separate UVLO). Keep it in mind while probing around.
Remove power to the peripherals during standby. This includes the sensors, the I2C pullups resistor, and the voltage divider to measure the cell voltage.

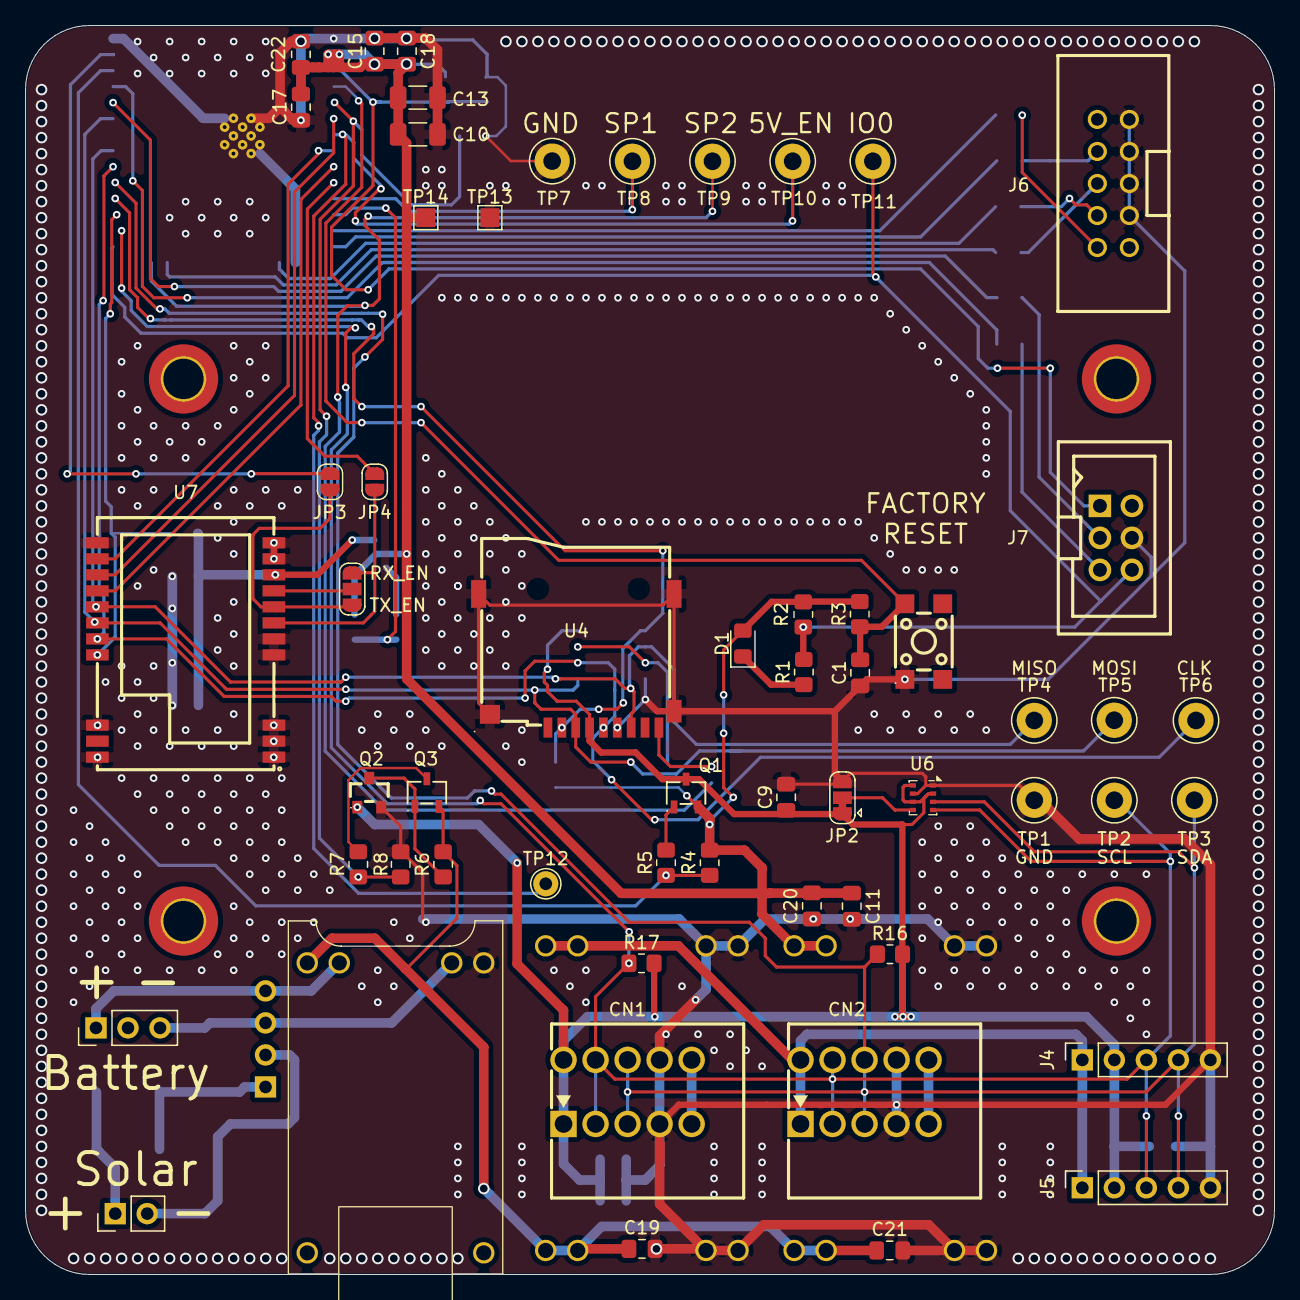
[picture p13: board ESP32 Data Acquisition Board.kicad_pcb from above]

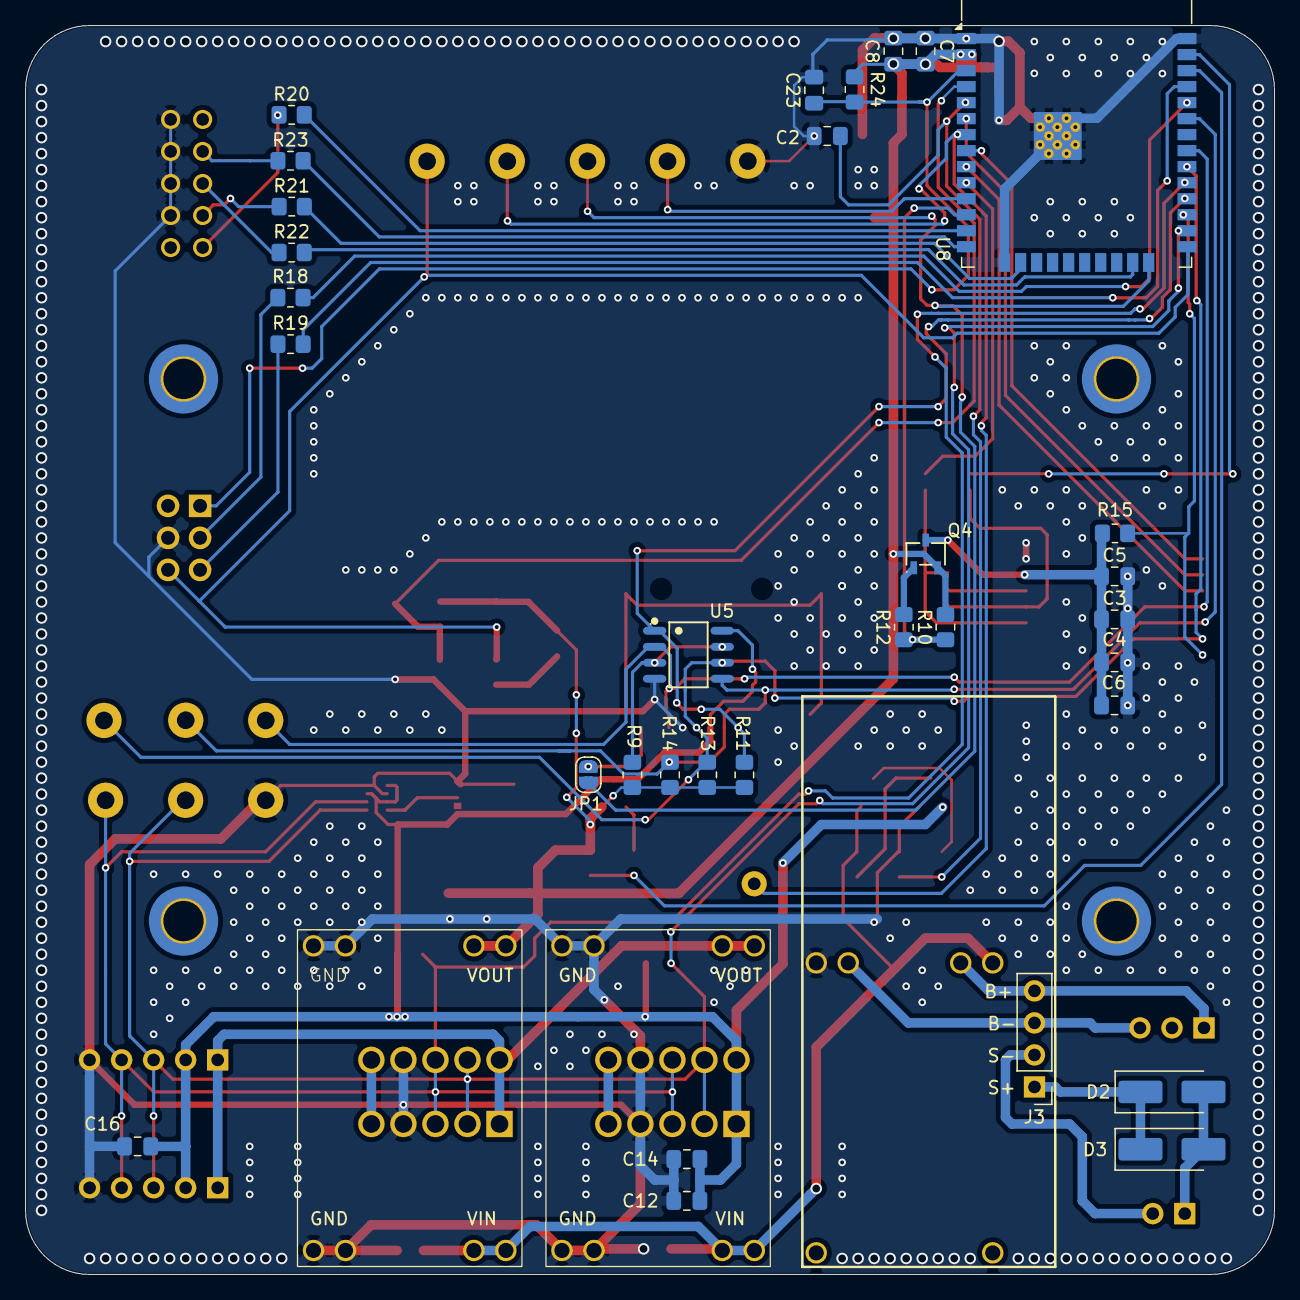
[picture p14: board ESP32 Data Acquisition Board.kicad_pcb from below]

Board: 2 copper layers, 99.1 x 99.1 mm, 91 parts (34 on the bottom side), 55 nets.

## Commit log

2026-06-07 Update README with project details and power management info
    Expanded the project description with details on development choices and power supply considerations.
2026-06-07 Updated readme, included interactive BoM, added 3D renders and schematics.
    [ESP32 Data Acquisition Board.kicad_pcb, ESP32 Data Acquisition Board.kicad_sch, ESP32-DevKitC-V4-(ESP32-SOLO-1)-BOMList(V1.2)-20180621A.xlsx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]
